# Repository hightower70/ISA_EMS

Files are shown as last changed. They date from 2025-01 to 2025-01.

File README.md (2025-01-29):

# 2MByte ISA EMS Expansion Card for IBM PC XT computers

This is a redesign of the **lo-tech.co.uk** [2Mb ISA EMS board](https://www.lo-tech.co.uk/wiki/Lo-tech_2MB_EMS_Board) with some changes:

- All thru-hole instead of SMD, while retaining a rather compact format
- Simplified address decoding and storage circuits for less chip count

All design files and gerber files for PCB manufacturing are avaiable in the repository. The schematics [schematics](schematics.pdf) is also avaiable in PDF format.

The card was tested in modern replica of an XT computer like Xi8088 and Micro8088 without issues.

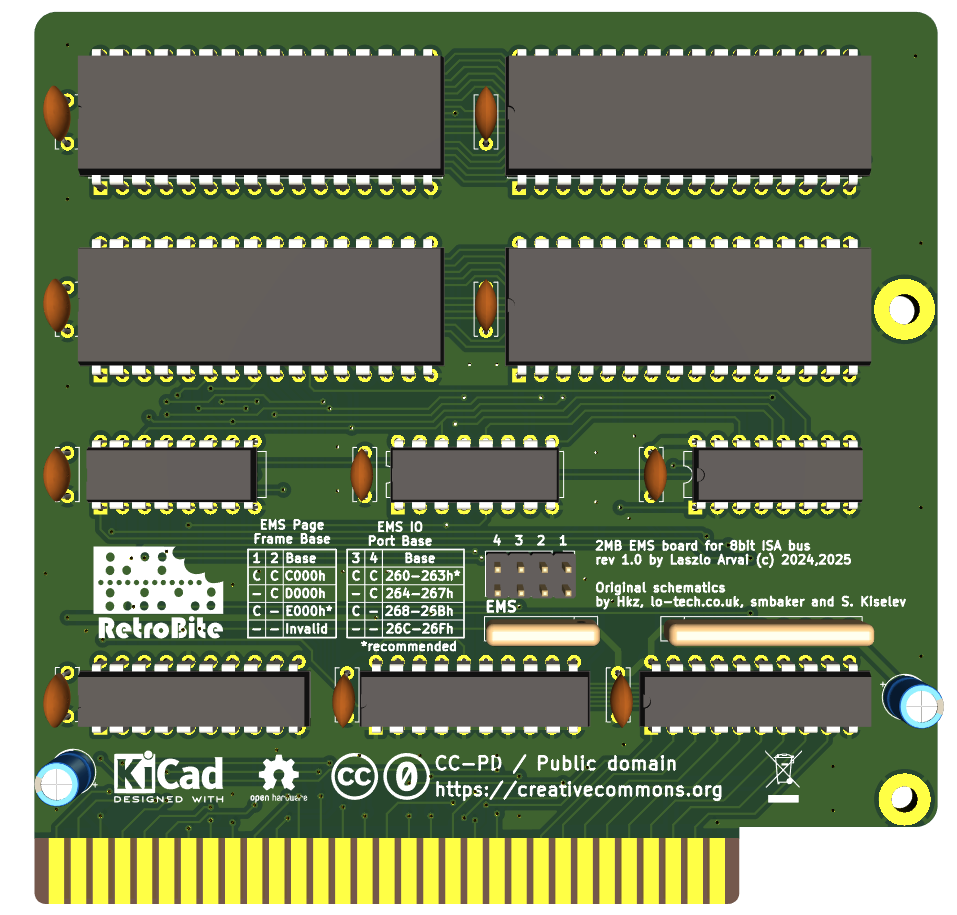
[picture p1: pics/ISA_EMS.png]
Rev. 1.0 PCB


## Configuration

To configure the EMS, jumpers on J2 header are used.

Pins pairs 1 and 2 configure the Page Frame base address, while 3 and 4 configure the IO Port base address.

Page Frame Address:

| 1 | 2 | EMS Page Frame Base |
| - | - | --- |
| X | X | C000h |
| - | X | D000h |
| X | - | E000h |
| - | - | Invalid |

Port Base Address

| 3 | 4 | EMS IO Port Base |
| - | - | --- |
| X | X | 260-263h |
| - | X | 264-267h |
| X | - | 268-26Bh |
| - | - | 26C-26Fh |

 (-=no jumper (opened), X=jumper (closed))

## Usage

You need a **memory manager** to use this board. I'm including the `LTEMM` driver provided by lo-tech in this repository. Please refer to [this](https://www.lo-tech.co.uk/wiki/Terms_and_Conditions) page regarding the terms of use.

## Bill of Materials

All ICs are in DIP package.

- C1,C4 ,C5 ,C6, C7, C8, C9, C10, C11, C12: 100nF, ceramic
- C2, C3: 10uF / 50v electrolytic caps
- J2 2x4 2.5mm breakable header
- RN1: resistor network, 10k, bussed, 5 pins
- RN2: resistor network, 10k, bussed, 9 pins. 
- U1, U2, U3, U4: AS6C4008-55PCN (You don't need to fill all sockets: fit as much memory as you need starting from socket 1!)
- U5: 74LS139
- U6: 74LS245
- U7, U10: 74HCT688
- U8, U9: 74LS670
- ISA bracket: Keystone 9202, plus screws.

## Credits

- Thanks to [hkzab](https://github.com/hkzlab/ISA_EMS_2Mb) for publishing a similar design
- Thanks to [lo-tech.co.uk](https://www.lo-tech.co.uk/) for having published their schematics
- Thanks to [Sergey](http://www.malinov.com/Home/sergeys-projects) for all his projects!

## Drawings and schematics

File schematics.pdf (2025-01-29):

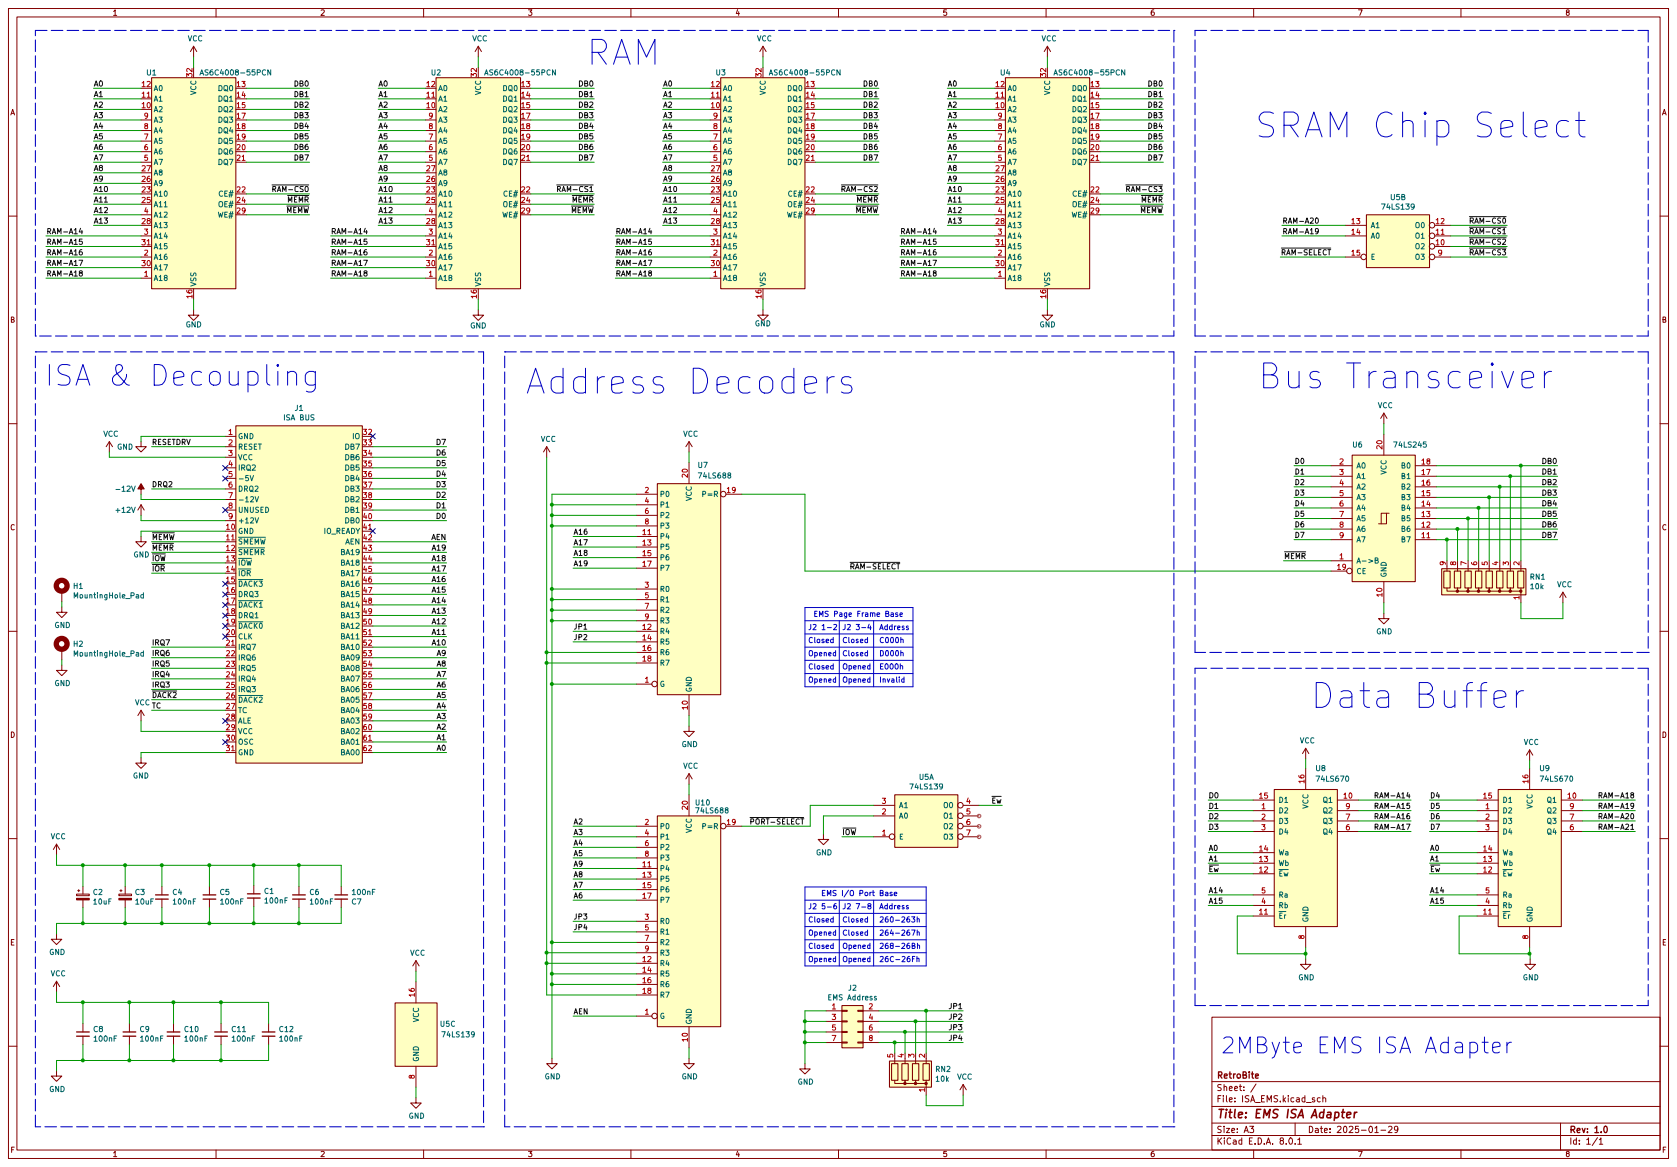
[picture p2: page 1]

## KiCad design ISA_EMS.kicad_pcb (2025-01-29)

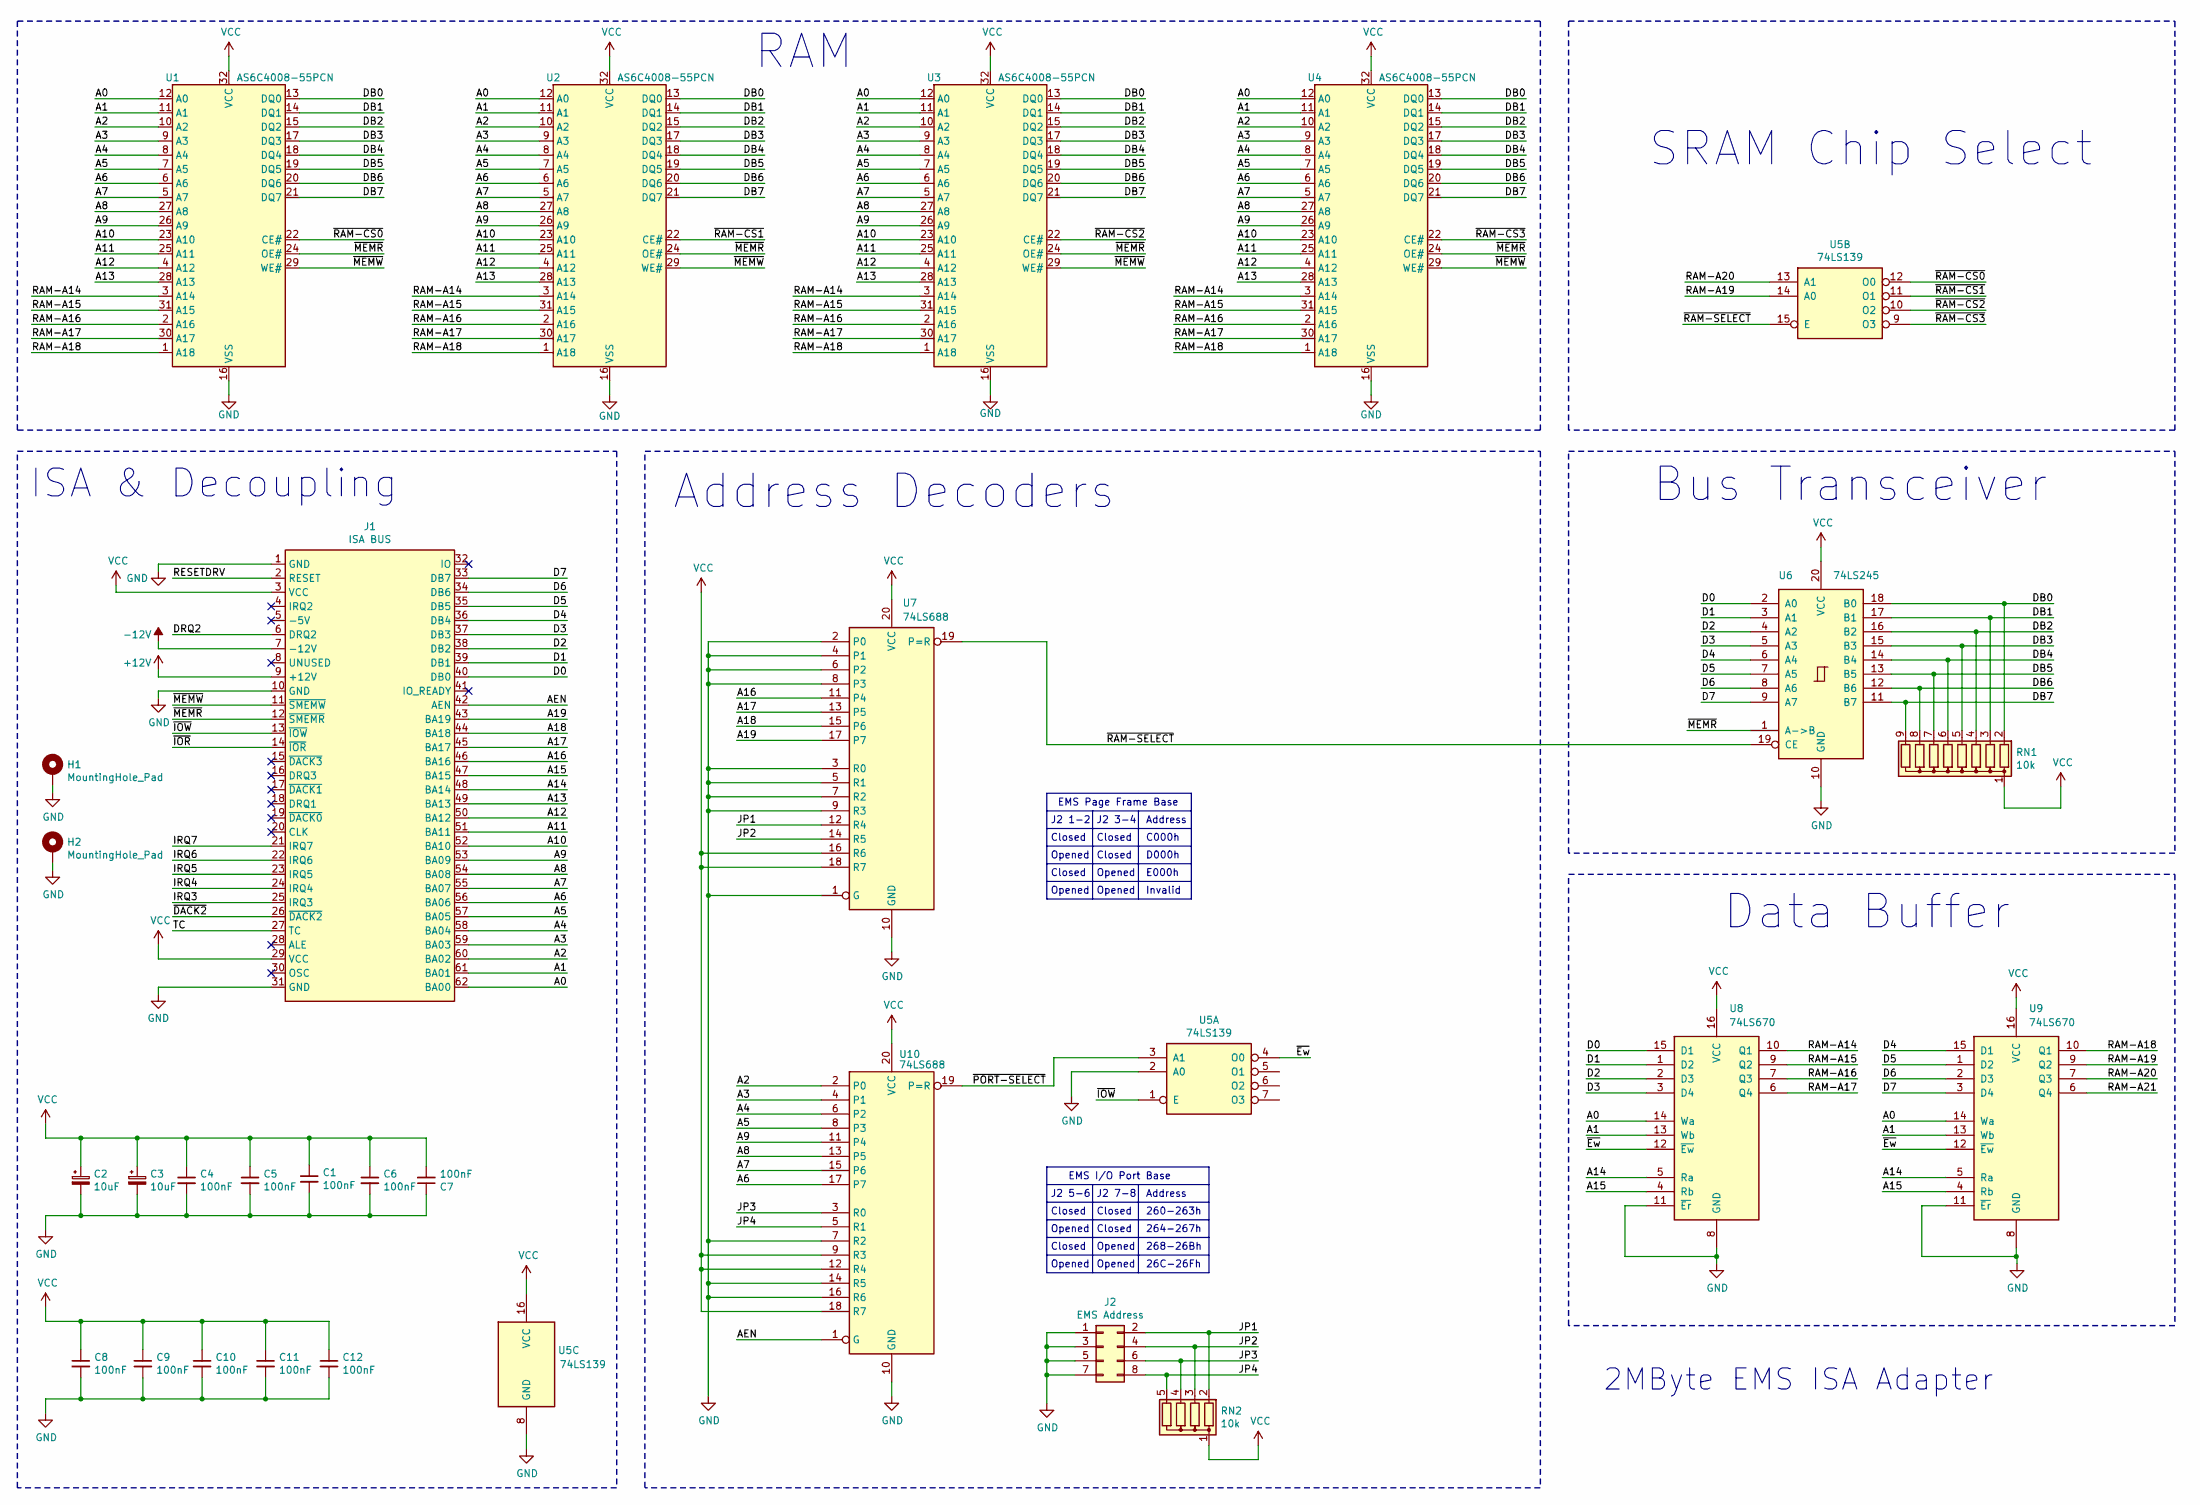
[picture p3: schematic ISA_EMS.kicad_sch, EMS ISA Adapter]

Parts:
C1, C4, C5, C6, C7, C8, C9, C10, C11, C12: 100nF; C_Disc_D6.0mm_W2.5mm_P5.00mm
C2, C3: 10uF; CP_Radial_D5.0mm_P2.50mm
H1: MountingHole_Pad; MountingHole_3mm_Pad
H2: MountingHole_Pad; MountingHole_3.5mm_Pad_TopBottom
J1: ISA BUS; BUS_XT
J2: EMS Address; PinHeader_2x04_P2.54mm_Vertical
RN1: 10k; R_Array_SIP9
RN2: 10k; R_Array_SIP5
U1, U2, U3, U4: AS6C4008-55PCN; DIP-32_W15.24mm
U5: 74LS139; DIP-16_W7.62mm
U6: 74LS245; DIP-20_W7.62mm
U7, U10: 74LS688; DIP-20_W7.62mm
U8, U9: 74LS670; DIP-16_W7.62mm

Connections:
+12V: J1.9 (+12V)
-12V: J1.7 (-12V)
/A0: J1.62 (BA00), U1.12 (A0), U2.12 (A0), U3.12 (A0), U4.12 (A0), U8.14 (Wa), U9.14 (Wa)
/A1: J1.61 (BA01), U1.11 (A1), U2.11 (A1), U3.11 (A1), U4.11 (A1), U8.13 (Wb), U9.13 (Wb)
/A2: J1.60 (BA02), U1.10 (A2), U2.10 (A2), U3.10 (A2), U4.10 (A2), U10.2 (P0)
/A3: J1.59 (BA03), U1.9 (A3), U2.9 (A3), U3.9 (A3), U4.9 (A3), U10.4 (P1)
/A4: J1.58 (BA04), U1.8 (A4), U2.8 (A4), U3.8 (A4), U4.8 (A4), U10.6 (P2)
/A5: J1.57 (BA05), U1.7 (A5), U2.7 (A5), U3.7 (A5), U4.7 (A5), U10.8 (P3)
/A6: J1.56 (BA06), U1.6 (A6), U2.6 (A6), U3.6 (A6), U4.6 (A6), U10.17 (P7)
/A7: J1.55 (BA07), U1.5 (A7), U2.5 (A7), U3.5 (A7), U4.5 (A7), U10.15 (P6)
/A8: J1.54 (BA08), U1.27 (A8), U2.27 (A8), U3.27 (A8), U4.27 (A8), U10.13 (P5)
/A9: J1.53 (BA09), U1.26 (A9), U2.26 (A9), U3.26 (A9), U4.26 (A9), U10.11 (P4)
/A10: J1.52 (BA10), U1.23 (A10), U2.23 (A10), U3.23 (A10), U4.23 (A10)
/A11: J1.51 (BA11), U1.25 (A11), U2.25 (A11), U3.25 (A11), U4.25 (A11)
/A12: J1.50 (BA12), U1.4 (A12), U2.4 (A12), U3.4 (A12), U4.4 (A12)
/A13: J1.49 (BA13), U1.28 (A13), U2.28 (A13), U3.28 (A13), U4.28 (A13)
/A14: J1.48 (BA14), U8.5 (Ra), U9.5 (Ra)
/A15: J1.47 (BA15), U8.4 (Rb), U9.4 (Rb)
/A16: J1.46 (BA16), U7.11 (P4)
/A17: J1.45 (BA17), U7.13 (P5)
/A18: J1.44 (BA18), U7.15 (P6)
/A19: J1.43 (BA19), U7.17 (P7)
/AEN: J1.42 (AEN), U10.1 (G)
/D0: J1.40 (DB0), U6.2 (A0), U8.15 (D1)
/D1: J1.39 (DB1), U6.3 (A1), U8.1 (D2)
/D2: J1.38 (DB2), U6.4 (A2), U8.2 (D3)
/D3: J1.37 (DB3), U6.5 (A3), U8.3 (D4)
/D4: J1.36 (DB4), U6.6 (A4), U9.15 (D1)
/D5: J1.35 (DB5), U6.7 (A5), U9.1 (D2)
/D6: J1.34 (DB6), U6.8 (A6), U9.2 (D3)
/D7: J1.33 (DB7), U6.9 (A7), U9.3 (D4)
/DB0: RN1.2 (R1), U1.13 (DQ0), U2.13 (DQ0), U3.13 (DQ0), U4.13 (DQ0), U6.18 (B0)
/DB1: RN1.3 (R2), U1.14 (DQ1), U2.14 (DQ1), U3.14 (DQ1), U4.14 (DQ1), U6.17 (B1)
/DB2: RN1.4 (R3), U1.15 (DQ2), U2.15 (DQ2), U3.15 (DQ2), U4.15 (DQ2), U6.16 (B2)
/DB3: RN1.5 (R4), U1.17 (DQ3), U2.17 (DQ3), U3.17 (DQ3), U4.17 (DQ3), U6.15 (B3)
/DB4: RN1.6 (R5), U1.18 (DQ4), U2.18 (DQ4), U3.18 (DQ4), U4.18 (DQ4), U6.14 (B4)
/DB5: RN1.7 (R6), U1.19 (DQ5), U2.19 (DQ5), U3.19 (DQ5), U4.19 (DQ5), U6.13 (B5)
/DB6: RN1.8 (R7), U1.20 (DQ6), U2.20 (DQ6), U3.20 (DQ6), U4.20 (DQ6), U6.12 (B6)
/DB7: RN1.9 (R8), U1.21 (DQ7), U2.21 (DQ7), U3.21 (DQ7), U4.21 (DQ7), U6.11 (B7)
/DRQ2: J1.6 (DRQ2)
/IRQ3: J1.25 (IRQ3)
/IRQ4: J1.24 (IRQ4)
/IRQ5: J1.23 (IRQ5)
/IRQ6: J1.22 (IRQ6)
/IRQ7: J1.21 (IRQ7)
/JP1: J2.2, RN2.2 (R1), U7.12 (R4)
/JP2: J2.4, RN2.3 (R2), U7.14 (R5)
/JP3: J2.6, RN2.4 (R3), U10.3 (R0)
/JP4: J2.8, RN2.5 (R4), U10.5 (R1)
/RAM-A14: U1.3 (A14), U2.3 (A14), U3.3 (A14), U4.3 (A14), U8.10 (Q1)
/RAM-A15: U1.31 (A15), U2.31 (A15), U3.31 (A15), U4.31 (A15), U8.9 (Q2)
/RAM-A16: U1.2 (A16), U2.2 (A16), U3.2 (A16), U4.2 (A16), U8.7 (Q3)
/RAM-A17: U1.30 (A17), U2.30 (A17), U3.30 (A17), U4.30 (A17), U8.6 (Q4)
/RAM-A18: U1.1 (A18), U2.1 (A18), U3.1 (A18), U4.1 (A18), U9.10 (Q1)
/RAM-A19: U5.14 (A0), U9.9 (Q2)
/RAM-A20: U5.13 (A1), U9.7 (Q3)
/RAM-A21: U9.6 (Q4)
/RESETDRV: J1.2 (RESET)
/TC: J1.27 (TC)
/~DACK2: J1.26 (~DACK2)
/~Ew: U5.4 (O0), U8.12 (~Ew), U9.12 (~Ew)
/~IOR: J1.14 (~IOR)
/~IOW: J1.13 (~IOW), U5.1 (E)
/~MEMR: J1.12 (~SMEMR), U1.24 (OE#), U2.24 (OE#), U3.24 (OE#), U4.24 (OE#), U6.1 (A->B)
/~MEMW: J1.11 (~SMEMW), U1.29 (WE#), U2.29 (WE#), U3.29 (WE#), U4.29 (WE#)
/~PORT-SELECT: U5.3 (A1), U10.19 (P=R)
/~RAM-CS0: U1.22 (CE#), U5.12 (O0)
/~RAM-CS1: U2.22 (CE#), U5.11 (O1)
/~RAM-CS2: U3.22 (CE#), U5.10 (O2)
/~RAM-CS3: U4.22 (CE#), U5.9 (O3)
/~RAM-SELECT: U5.15 (E), U6.19 (CE), U7.19 (P=R)
GND: C1.2, C2.2, C3.2, C4.2, C5.2, C6.2, C7.1, C8.2, C9.2, C10.2, C11.2, C12.2, H1.1, H2.1, J1.1 (GND), J1.10 (GND), J1.31 (GND), J2.1, J2.3, J2.5, J2.7, U1.16 (VSS), U2.16 (VSS), U3.16 (VSS), U4.16 (VSS), U5.2 (A0), U5.8 (GND), U6.10 (GND), U7.1 (G), U7.2 (P0), U7.3 (R0), U7.4 (P1), U7.5 (R1), U7.6 (P2), U7.7 (R2), U7.8 (P3), U7.9 (R3), U7.10 (GND), U8.8 (GND), U8.11 (~Er), U9.8 (GND), U9.11 (~Er), U10.7 (R2), U10.10 (GND), U10.14 (R5), U10.16 (R6)
VCC: C1.1, C2.1, C3.1, C4.1, C5.1, C6.1, C7.2, C8.1, C9.1, C10.1, C11.1, C12.1, J1.3 (VCC), J1.29 (VCC), RN1.1 (common), RN2.1 (common), U1.32 (VCC), U2.32 (VCC), U3.32 (VCC), U4.32 (VCC), U5.16 (VCC), U6.20 (VCC), U7.16 (R6), U7.18 (R7), U7.20 (VCC), U8.16 (VCC), U9.16 (VCC), U10.9 (R3), U10.12 (R4), U10.18 (R7), U10.20 (VCC)

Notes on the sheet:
Closed
C000h
J2 5-6
26C-26Fh
2MByte EMS ISA Adapter
D000h
SRAM Chip Select
Bus Transceiver
EMS Page Frame Base
Invalid
EMS I/O Port Base
Address
Address Decoders
264-267h
J2 7-8
Opened
Data Buffer
ISA & Decoupling
J2 3-4
268-26Bh
RAM
E000h
J2 1-2
260-263h

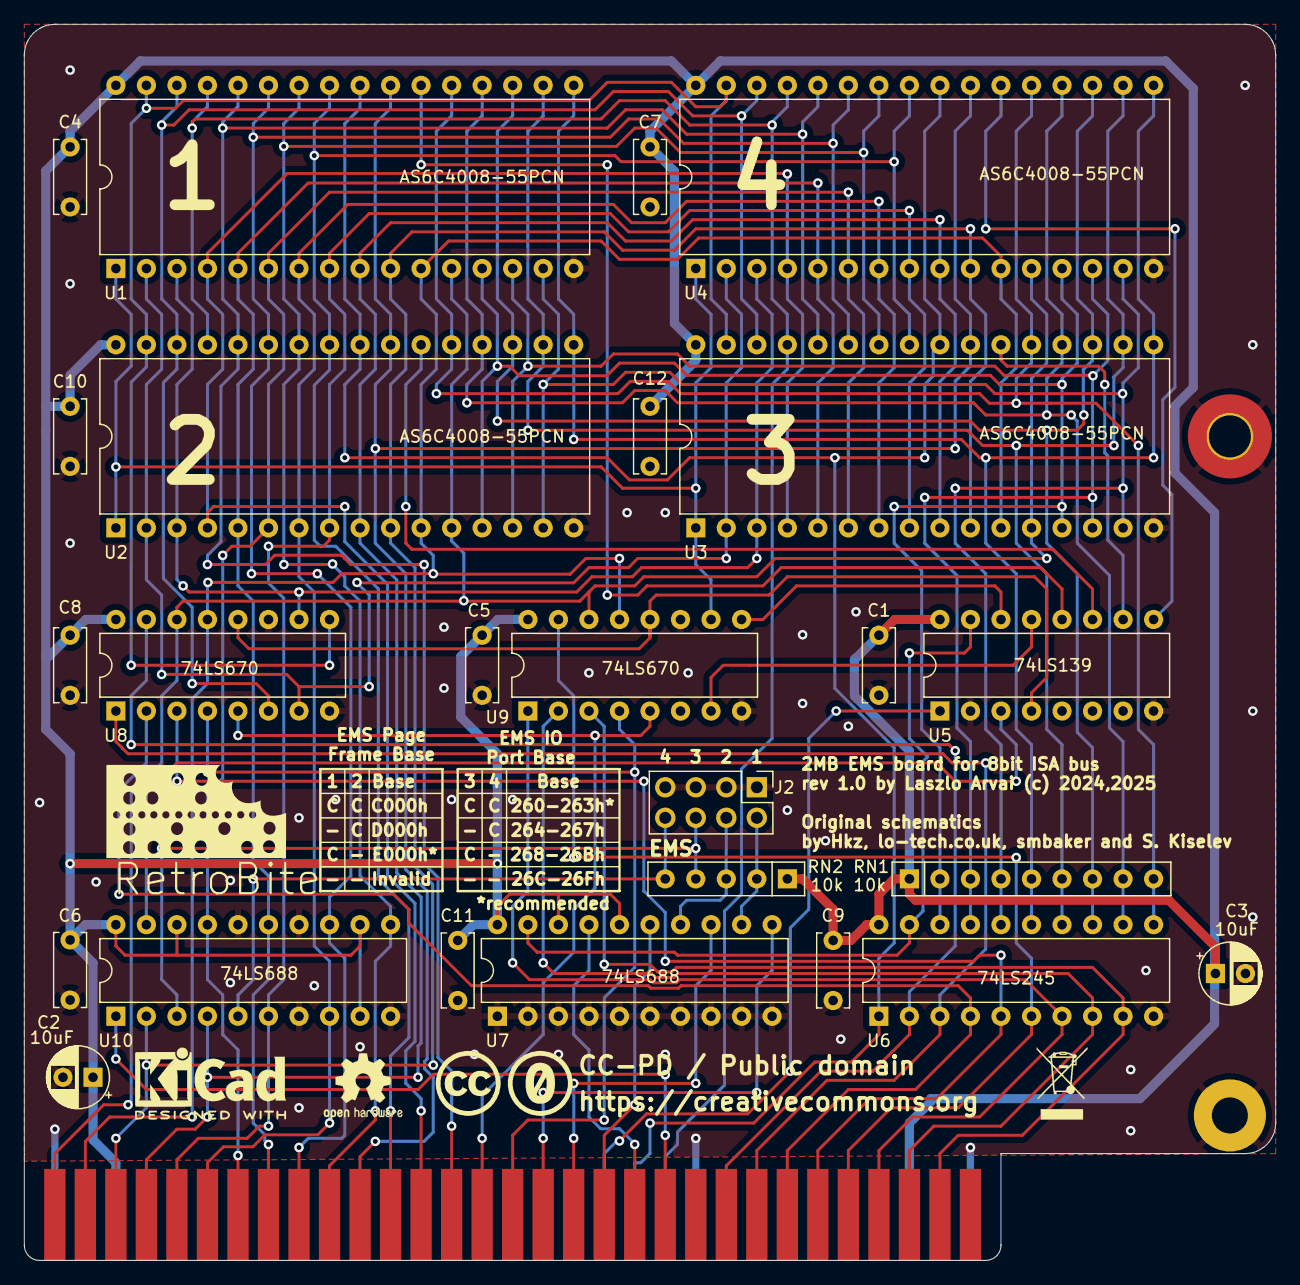
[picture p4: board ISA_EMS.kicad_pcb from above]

Board: 2 copper layers, 104.1 x 102.9 mm, 28 parts (0 on the bottom side), 60 nets.

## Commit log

2025-01-29 Gerber files has been added
    [ISA_EMS-B_Cu.gbl, ISA_EMS-B_Mask.gbs, ISA_EMS-B_Paste.gbp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]
2025-01-29 Schematics has been added
2025-01-29 PCB update
    [ISA_EMS.kicad_pcb]

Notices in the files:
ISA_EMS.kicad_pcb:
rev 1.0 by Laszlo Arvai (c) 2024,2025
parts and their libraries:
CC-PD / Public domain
